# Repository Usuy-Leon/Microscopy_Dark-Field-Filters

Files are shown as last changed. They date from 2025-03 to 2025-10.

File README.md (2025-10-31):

<div align="center">
<div style="background-color: #1a1b1e; padding: 20px; border-radius: 8px; margin-bottom: 20px;">

# DIY Dark-Field Filters

An open-source filter for a custom dark-field setup that can be adapted to any compound microscope. 🔬🔬

darkField

This 3D-printed / laser-cut design is created for contrast illumination techniques, aimed at microscopy enthusiasts and professionals.

<hr>
</div>
<div align="left">
 
# Why Improve Contrast?
In microscopy, a lot of samples especially those that aren’t stained or are still alive have such low contrast that even with a good microscope lens, important details are hard to see. improving contrast is key to making these details visible without messing up or damaging the sample.

# How to use it for 3D printing?

Simply download the correct STL file for your prints.

>

video1

<div align="left">
 
# Want to customize the design for your own specific objective or microscope?

> **Alternatively:**
>  You can download the OpenScad file (1 file for folder) and **very easily** edit each parameter of the filter.
 
- [ ] Download and install OpenScad (Free an open sofware for CAD files)
   - " https://openscad.org/downloads.html "
- [ ] Open the file using the program and look for parameters of the filter

    

- [ ] Simply edit to your needs
   - All measurement are in milimiters
- [ ] Generate a new STL file, save it and you are ready to print.

# How to use it for Laser cutting?

- [ ] Import the STL file into your laser cutting software:
   - Most popular laser cutting software supports importing STL files directly

- [ ] Scale and position the object:
   - Adjust the size and orientation of the object as needed

- [ ] Set material properties:
   - Input the thickness and type of material you'll be cutting
- [ ] Start the cutting 

# How to use a spider stop ?

Most microscopes have a way to add a filter in the optical path between the ilumination and the condenser.

</div>
<div align="center">


(Taken from Abramowitz, Olympus Corporation 1990)

</div>
<div align="left">

The diameter of the opaque stop should be approximately 8mm for the 10X objective of N.A. 0.25 to approximately 15mm for objectives of N.A. 0.65.

</div>
<div align="center">



</div>
<div align="left">

> **MAKE SURE !**
>  1. Your condenser is as close to the sample as possible !
>  2. The Field Diafragm is at least 90 % open !
>  3. Beyond 0.65 NA Spider stop filters are harder to use and allign !

# This is How it looks!

</div>
<div align="center">

daph_Dark

Daphnia sp, 25x, Custume Dark Field

</div>
<div align="left">

# For the spanish version check the LEEME.md!

# Recomended readings
   - Abramowitz, Mortimer; Microscope Basics and Beyond Vol, 2; Olympus Corporation 1990
   - Bradbury, Savile; An Introduction to Light Microscopy; Oxford University Press 1984
   - Hartley, W.G.; Hartley's Microscopy; Senecio Publishers Limited 1979
   - Hoffman, Robert; The Modulation Contrast Microscope; Journal of Microscopy Vol. 110 pt. 3 August 1977

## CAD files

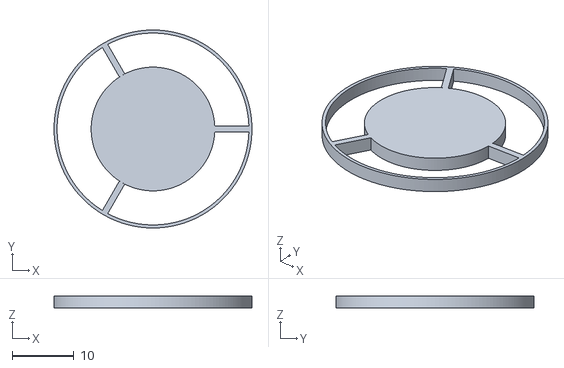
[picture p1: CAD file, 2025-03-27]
32mm_DarkFilters_STL/DarkFilter_s32mm_p20mm.stl
32.0 x 32.0 x 2.00

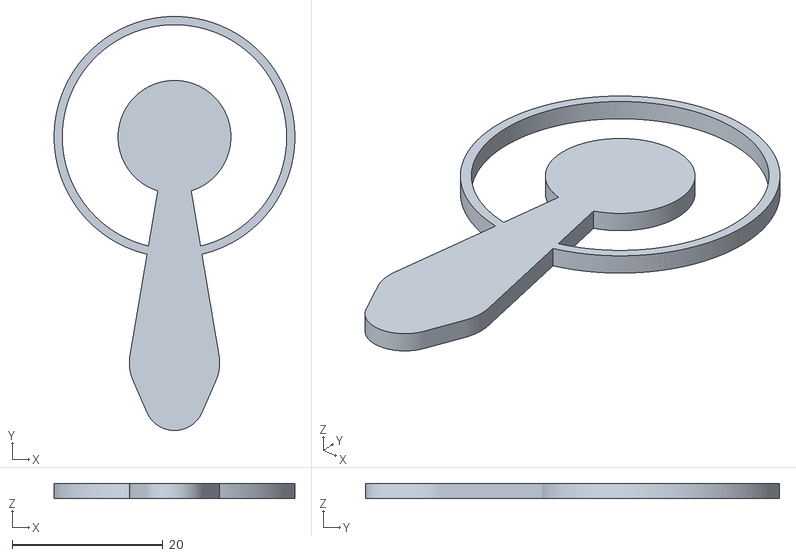
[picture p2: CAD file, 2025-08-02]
Hand_holder_Darkfilter_32mm/Side_Ilumination_triangle_Template.stl
32.0 x 55.0 x 2.00

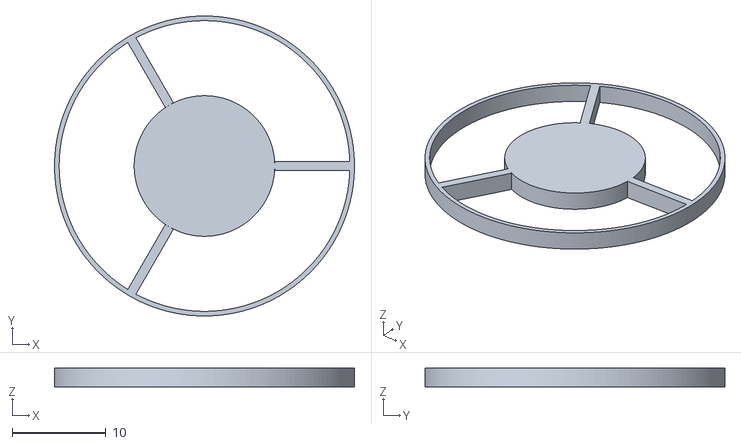
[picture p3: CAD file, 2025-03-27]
32mm_DarkFilters_STL/DarkFilter_s32mm_p15mm.stl
32.0 x 32.0 x 2.00

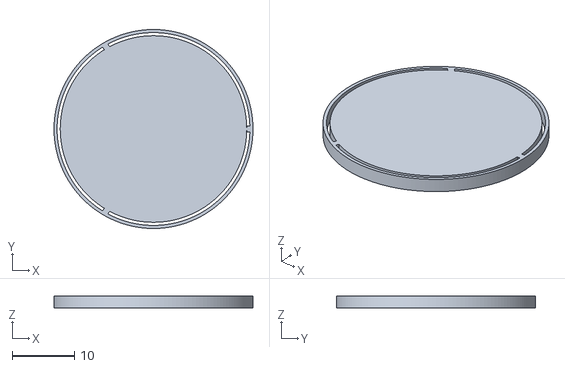
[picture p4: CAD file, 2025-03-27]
32mm_DarkFilters_STL/DarkFilter_s32mm_p30mm.stl
32.0 x 32.0 x 2.00

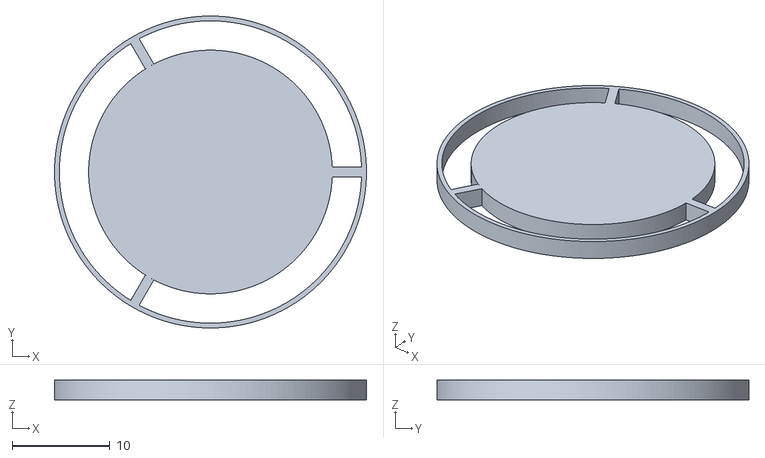
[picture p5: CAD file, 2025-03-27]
32mm_DarkFilters_STL/DarkFilter_s32mm_p25mm.stl
32.0 x 32.0 x 2.00

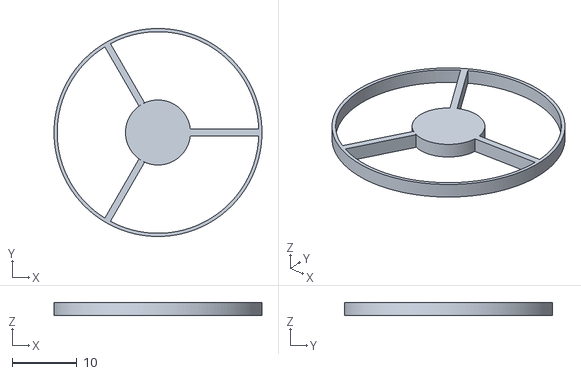
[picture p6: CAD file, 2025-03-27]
32mm_DarkFilters_STL/DarkFilter_s32mm_p10mm.stl
32.0 x 32.0 x 2.00

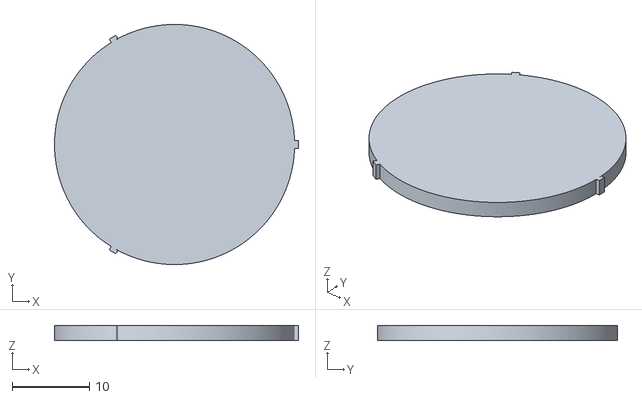
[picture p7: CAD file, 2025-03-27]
32mm_DarkFilters_STL/DarkFilter_s32mm_p31mm.stl
31.5 x 31.0 x 2.00

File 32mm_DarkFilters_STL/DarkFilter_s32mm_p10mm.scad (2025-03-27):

/* 
                            Dark Field Filters v1.0
                    
   Dark Field Filters v1.0

An open source filter for a costume dark field hat can be adapted to any compound microscope.

This 3D file is designed to be the first optical filter for contrast illumination Technics for microscopy enthusiast and professionals.
     
Source :https://github.com/Usuy-Leon/DIY_Dark-Field-Filters

This project is an Open Source project,
by Usuy D. Leon, 2025.03.26
Microscopist, National University of Colombia, Bogota DC,

    */

// // // // // // // // // // // // // // // // // // // // // // // // // //
/*                        - User Parameters -                             */
 
height = 3;         // Total height of the filter
outer_dia = 32;     // Outer diameter of the main structure
inner_dia = 10;     // Diameter of the light-blocking center cylinder
border_thickness = 2; // Thickness of the outer border
$fn = 150;          // Number of facets "resolution"

/*                      - Arms Characteristics -                          */

number_arms = 3;    // less arms will give you more information and light
arm_thickness = 1;  // Thickness of the connecting arms


// // // // // // // // // // // // // // // // // // // // // // // // // // 
/*                            - Filter Caracteristics -                    */

// Calculate the border ring
border_inner_dia = outer_dia - border_thickness;

// Create the outer border ring
difference() {
    cylinder(h=height, d=outer_dia);
    cylinder(h=2+height, d=border_inner_dia);
}

// Create the central light-blocking cylinder
cylinder(h=height, d=inner_dia);

for (i = [0:number_arms-1]) {
    rotate([0, 0, i*(360/number_arms)]) {
        translate([inner_dia/2, -arm_thickness/2, 0]) {
            cube([
                (border_inner_dia/2 - inner_dia/2), // Arm length
                arm_thickness,
                height
            ]);
        }
    }
}
